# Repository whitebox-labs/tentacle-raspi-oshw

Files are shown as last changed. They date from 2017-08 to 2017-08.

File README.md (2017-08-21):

# The Tentacle T3 for Raspberry Pi

Tentacle T3 for Raspberry Pi

These are the hardware source files for the Tentacle T3 - an add-on board for Raspberry Pi to interface with Atlas Scientific sensor circuits.

Full documentation is here: https://www.whiteboxes.ch/tentacle

If you find bug in the examples or the schematic, feel free to create an issue or even a pull request here on GitHub. For help and user support, please use the form on our website.

License of pcb schematics and layout: http://creativecommons.org/licenses/by-sa/4.0/
Licence: https://creativecommons.org/licenses/by-sa/4.0/
Creative Commons Attribution-ShareAlike 4.0 International

Silkscreen graphics and the trade mark "Tentacle T3" are intellectual property of Whitebox Labs (please create your own graphics ;)).

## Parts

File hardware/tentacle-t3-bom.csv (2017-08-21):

Id | Description | Package | Qty | Designator | Designation
1 | 2x40-pin female header .1inch | .1 inch header | 1 | PI_BOARD101 | RASPBERRY_PI_2
2 | LDO voltage regulator | SOT89 | 2 | REG201,REG301 | LD2981ABU50TR
3 | Digital signal isolator | SOIC-8 | 2 | SIG_ISO201, SIG_ISO301 | SI8600
4 | SMD resistor 4.7K, 1/8W | SM0805 | 6 | R101, R102, R201, R202, R301, R302 | 4.7K
5 | Multilayer Ceramic Capacitor 0.1uF | SM0805 | 4 | C204, C205, C304, C305 | 0.1 µF
6 | Multilayer Ceramic Capacitor 1uF | SM0805 | 4 | C201, C202, C301, C302 | 1µF
7 | Multilayer Ceramic Capacitor 2.2uF | SM0805 | 2 | C203, C303 | 2.2µF
8 | Tantalum Capacitor 470uF | C_TANT_CASE_X | 1 | C101 | 470µF
9 | Isolated DC/DC converter 5V | R1SE_0505 | 2 | DCDC201,DCDC301 | R1SE_0505
10 | BNC Connector | BNC-1337542 | 3 | P201,P301 | BNC
11 | 1x3-pin female header .1inch | 1x3 .1 inch spacing female pin | 6 | STP201,STP301 | ATLAS_STAMP
12 | 1x6-pin male header .1inch | 1x6 .1 inch spacing male pin | 2 | P101, P102 | CONN_01X06

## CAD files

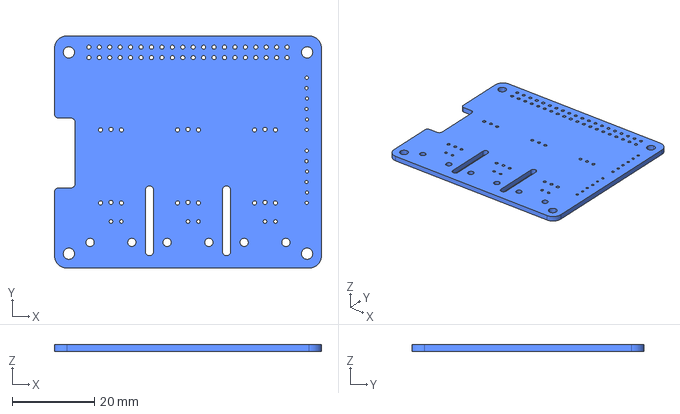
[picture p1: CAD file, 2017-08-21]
hardware/KiCad/tentacle-raspi.step
65.0 x 56.5 x 1.60 mm

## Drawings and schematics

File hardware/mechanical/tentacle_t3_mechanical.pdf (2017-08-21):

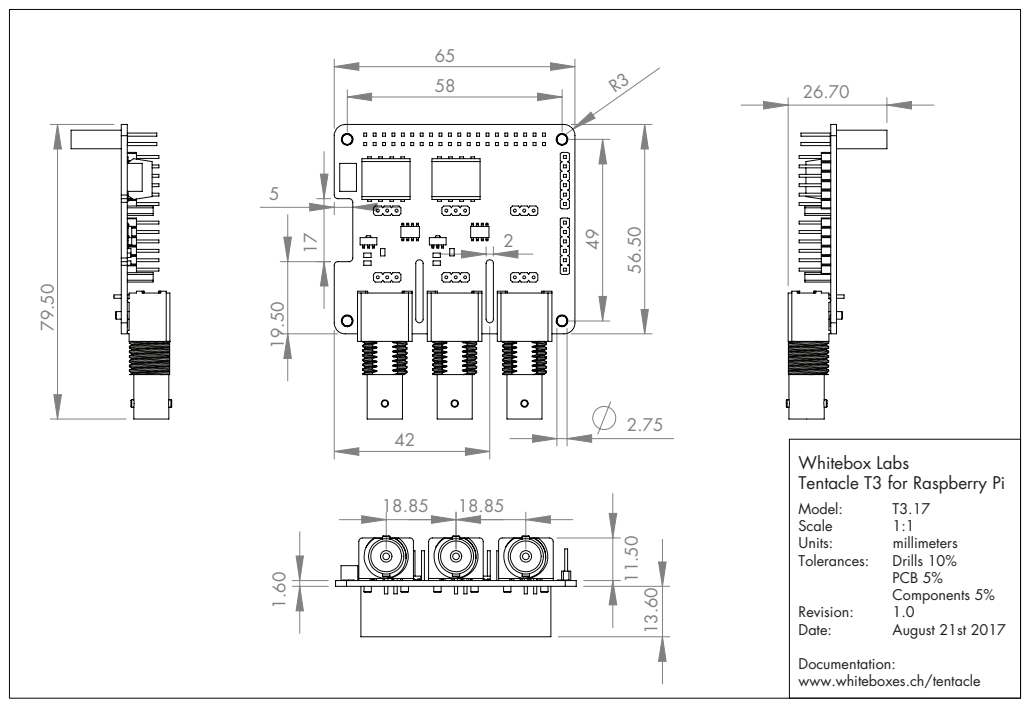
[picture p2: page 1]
Model:; Scale; Units:; millimeters; Tolerances:; Drills 10%; PCB 5% Components 5%; Revision:; Date:; August 21st 2017

Whitebox Labs
Tentacle T3 for Raspberry Pi

Documentation:
www.whiteboxes.ch/tentacle

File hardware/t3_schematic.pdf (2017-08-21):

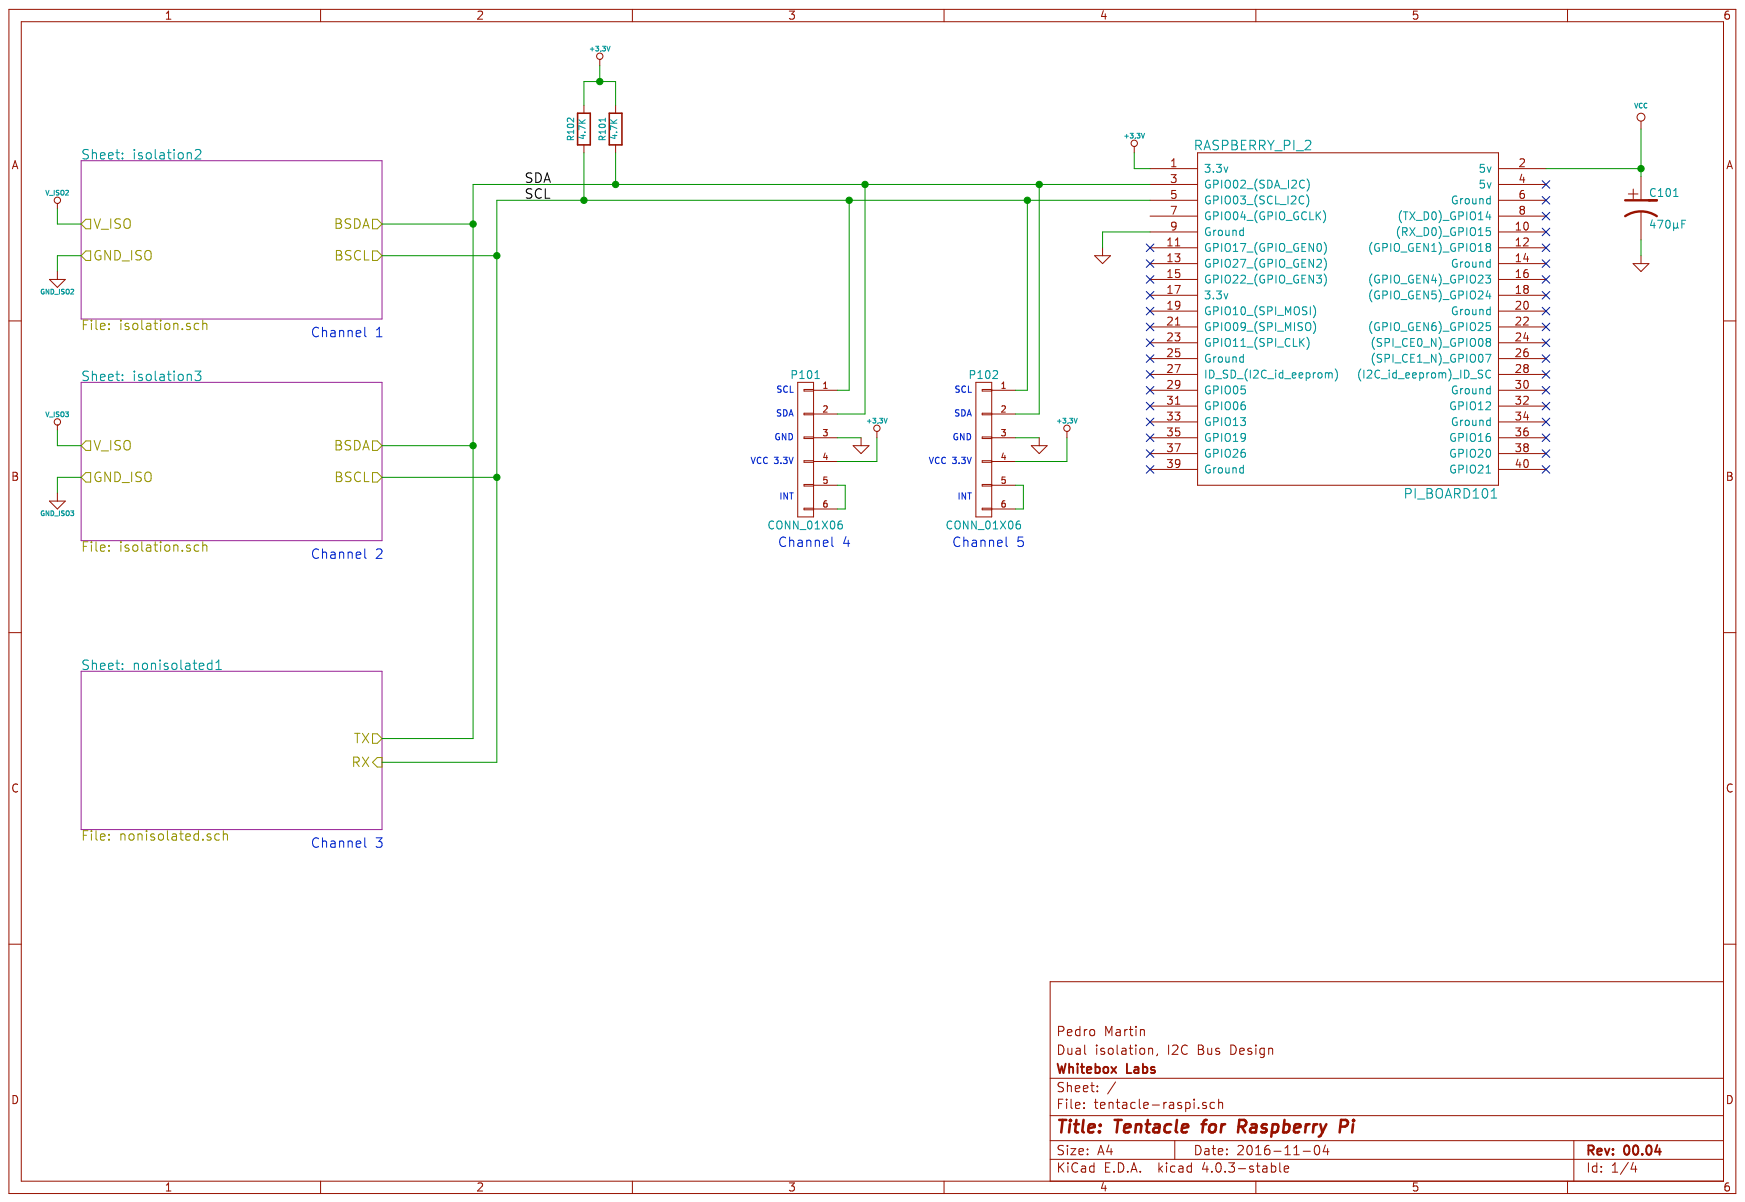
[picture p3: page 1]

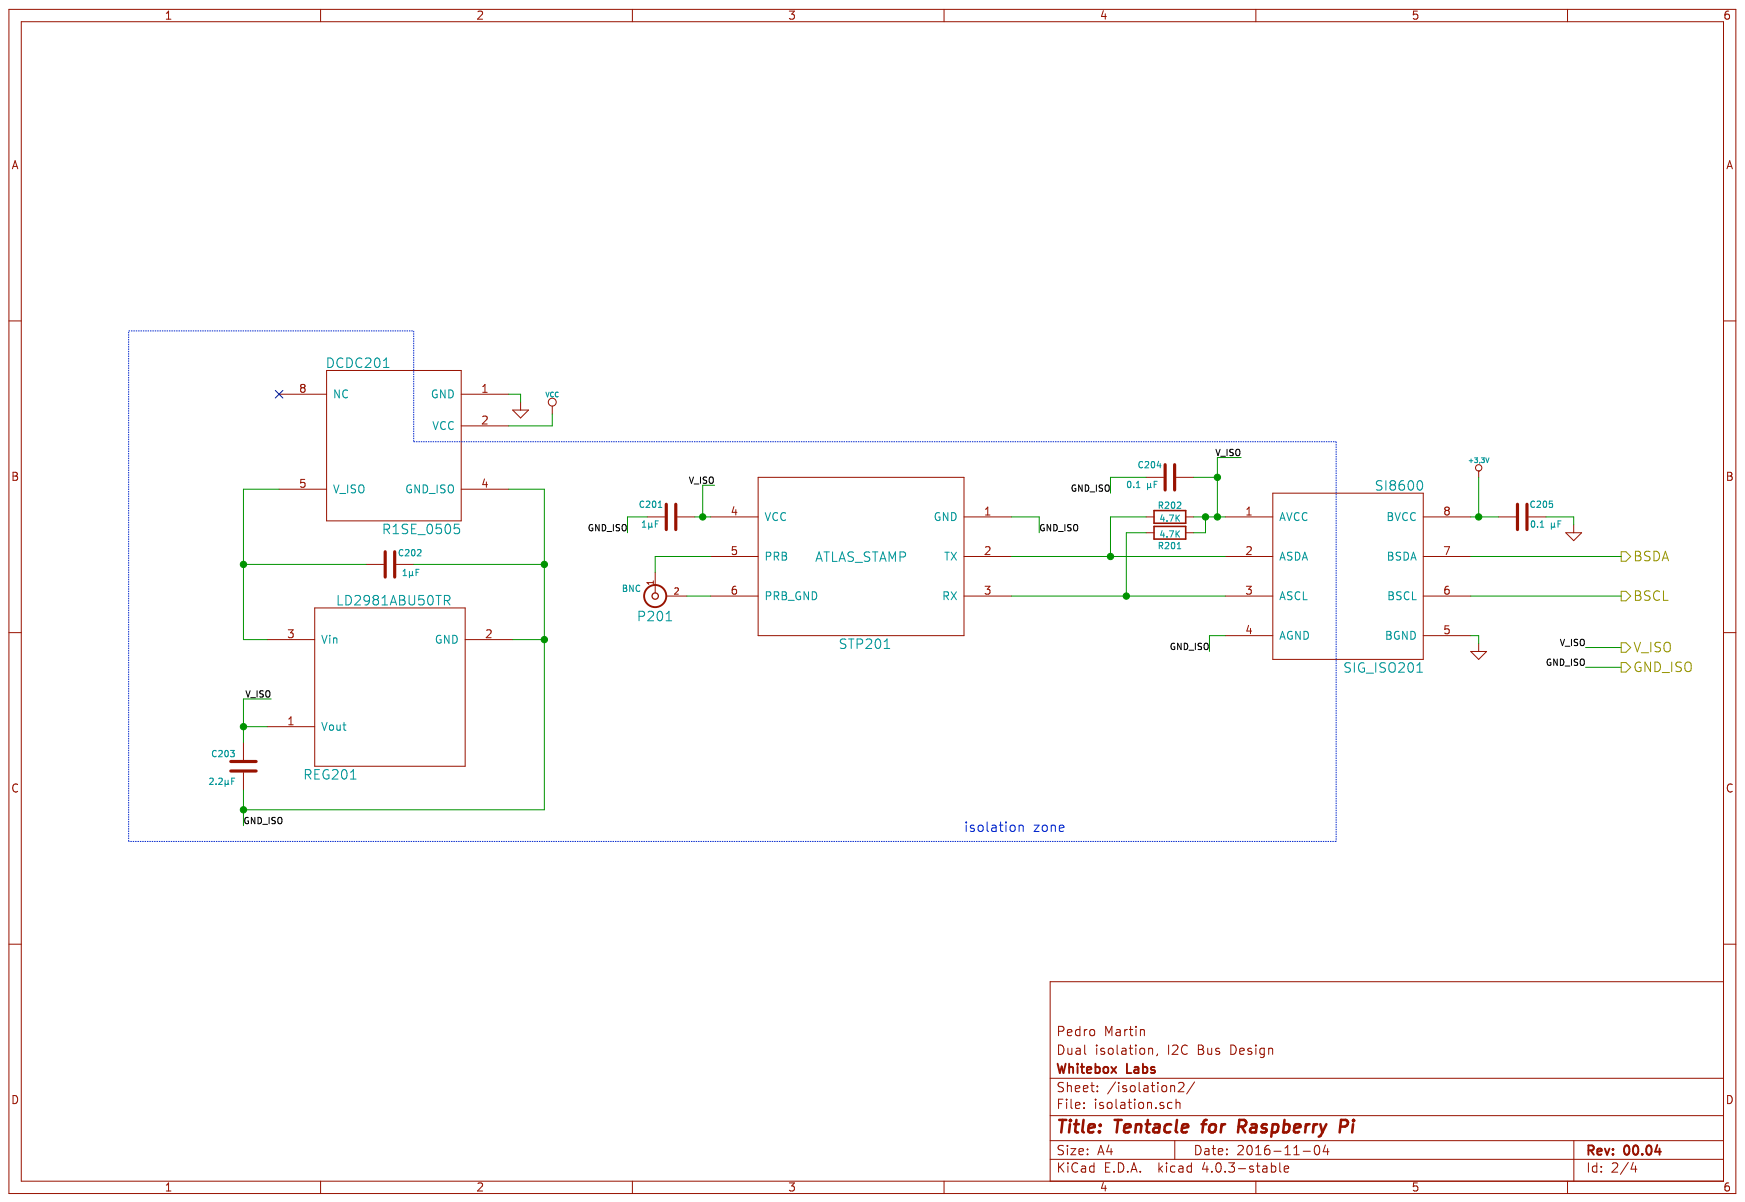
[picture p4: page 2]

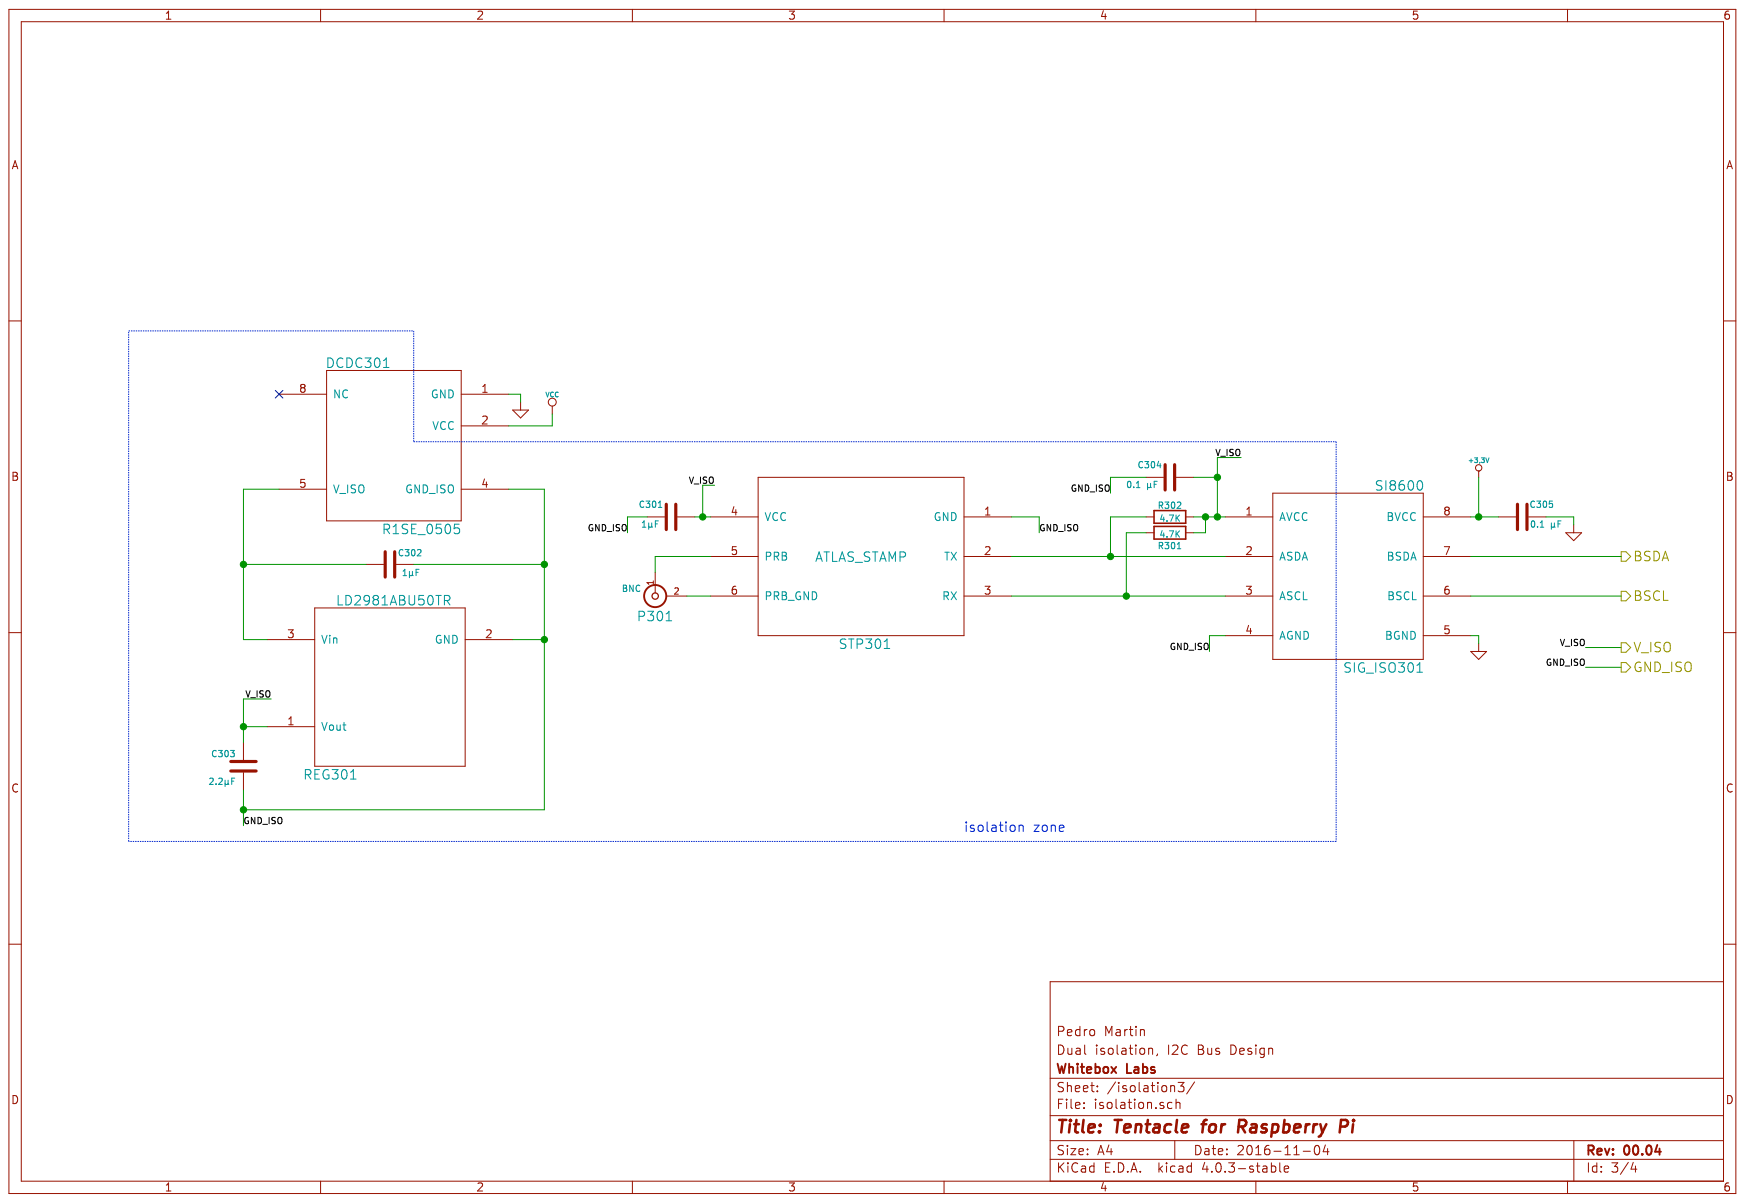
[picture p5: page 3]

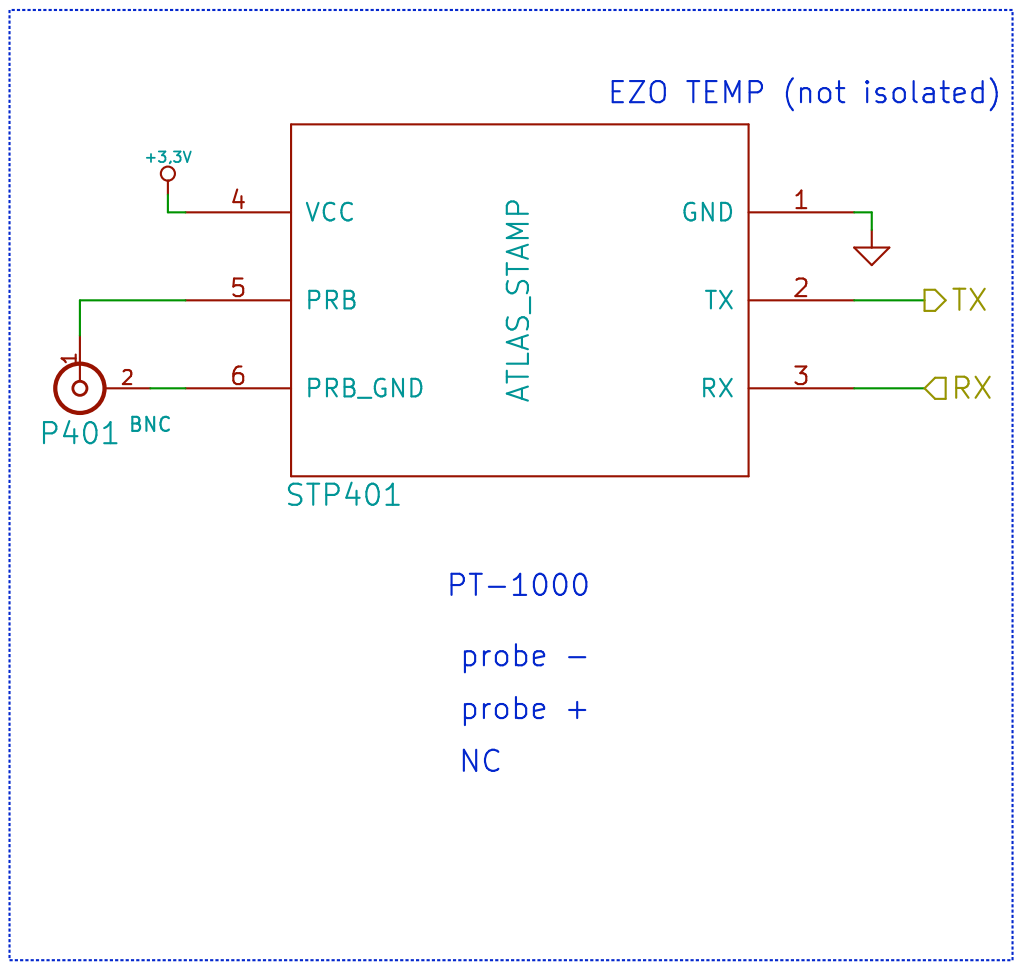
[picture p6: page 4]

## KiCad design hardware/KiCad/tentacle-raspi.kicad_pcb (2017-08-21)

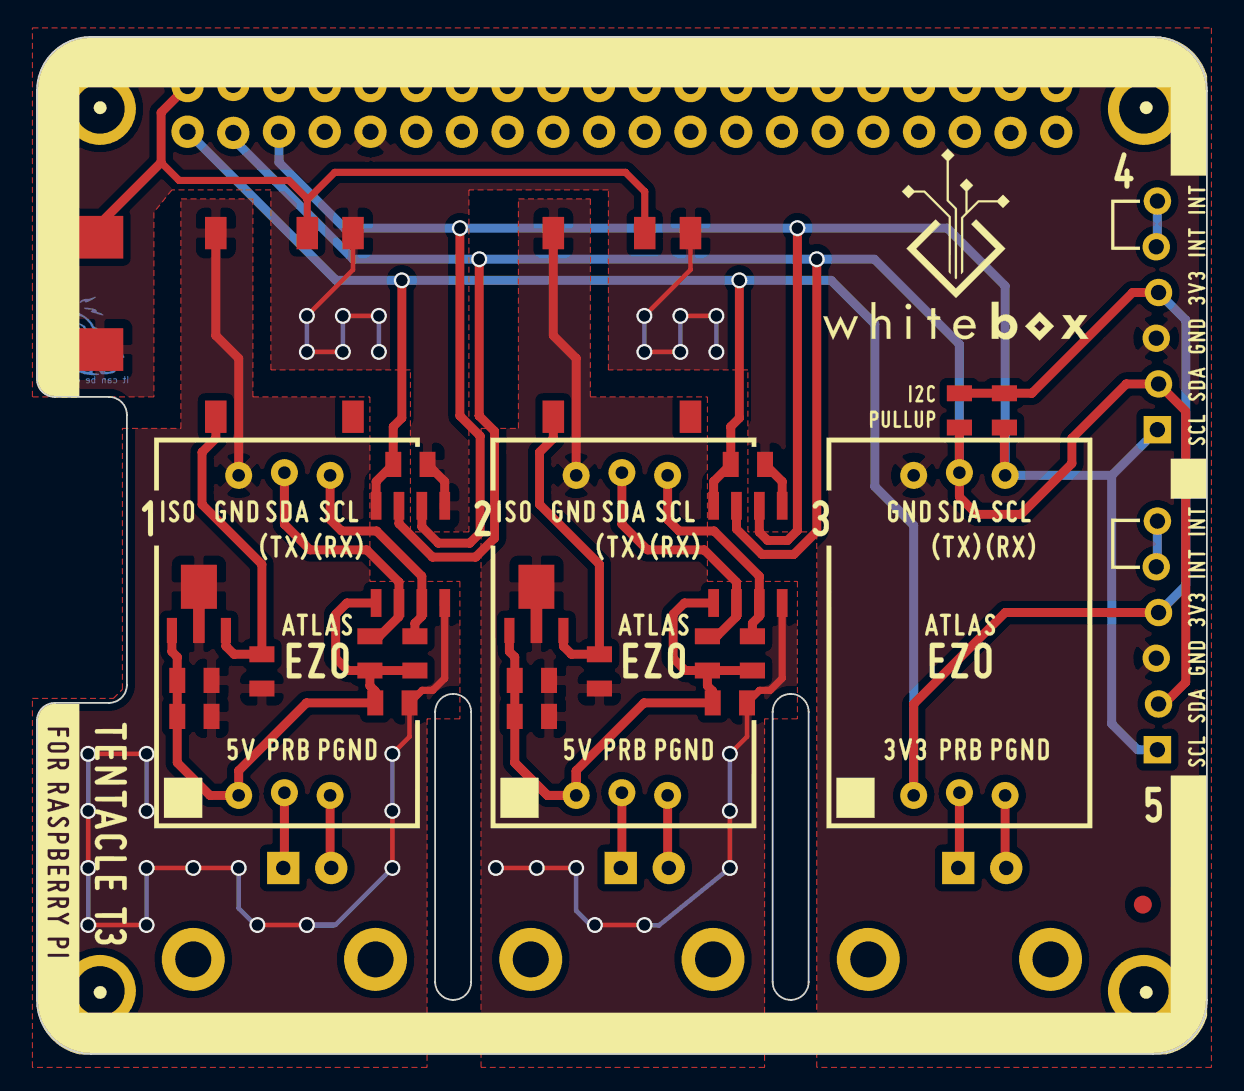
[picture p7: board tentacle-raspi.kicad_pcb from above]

Board: 2 copper layers, 65.0 x 56.5 mm, 37 parts (1 on the bottom side), 23 nets.

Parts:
BOT: LOGO; WL-BOT-T3
C101: 470µF; WL-CASE-X-2917
C201, C202, C301, C302: 1µF; WL-SM0805C
C203, C303: 2.2µF; WL-SM0805C
C204, C205, C304, C305: 0.1 µF; WL-SM0805C
DCDC201, DCDC301: R1SE_0505; WL-R1SE-0505
P101, P102: CONN_01X06; WL-PINH_1X6_snk
P201, P301, P401: BNC; WL-EB08040502_snk
PI_BOARD101: RASPBERRY_PI_2; WL-40pin_snk
PI_Board: VAL**; WL-PI_Board_no_outline
R101, R102, R201, R202, R301, R302: 4.7K; WL-SM0805R
REG201, REG301: LD2981ABU50TR; WL-SOT89
SIG_ISO201, SIG_ISO301: SI8600; WL-SOIC8N
STP201, STP301, STP401: ATLAS_STAMP; WL-ezo-19454_snk
TOP: LOGO; WL-TOP-T3
fiducial: VAL**; WL-fiducial_1mm
fiducial#2: VAL**; WL-fiducial_1mm

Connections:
+3.3V: C205.1, C305.1, P101.4, P102.4, PI_BOARD101.1, R101.2, R102.2, SIG_ISO201.8, SIG_ISO301.8, STP401.4
/SCL: P101.1, P102.1, PI_BOARD101.5, R102.1, SIG_ISO201.6, SIG_ISO301.6, STP401.3
/SDA: P101.2, P102.2, PI_BOARD101.3, R101.1, SIG_ISO201.7, SIG_ISO301.7, STP401.2
GND: C101.2, C205.2, C305.2, DCDC201.1, DCDC301.1, P101.3, P102.3, PI_BOARD101.9, SIG_ISO201.5, SIG_ISO301.5, STP401.1
GND_ISO2: C201.1, C202.1, C203.1, C204.1, DCDC201.4, REG201.2, SIG_ISO201.4, STP201.1
GND_ISO3: C301.1, C302.1, C303.1, C304.1, DCDC301.4, REG301.2, SIG_ISO301.4, STP301.1
unnamed: C202.2, DCDC201.5, REG201.3
unnamed: C302.2, DCDC301.5, REG301.3
unnamed: P101.5, P101.6
unnamed: P102.5, P102.6
unnamed: P201.1, STP201.5
unnamed: P201.2, STP201.6
unnamed: P301.1, STP301.5
unnamed: P301.2, STP301.6
unnamed: P401.1, STP401.5
unnamed: P401.2, STP401.6
unnamed: R201.2, SIG_ISO201.3, STP201.3
unnamed: R202.2, SIG_ISO201.2, STP201.2
unnamed: R301.2, SIG_ISO301.3, STP301.3
unnamed: R302.2, SIG_ISO301.2, STP301.2
VCC: C101.1, DCDC201.2, DCDC301.2, PI_BOARD101.2
V_ISO2: C201.2, C203.2, C204.2, R201.1, R202.1, REG201.1, SIG_ISO201.1, STP201.4
V_ISO3: C301.2, C303.2, C304.2, R301.1, R302.1, REG301.1, SIG_ISO301.1, STP301.4
